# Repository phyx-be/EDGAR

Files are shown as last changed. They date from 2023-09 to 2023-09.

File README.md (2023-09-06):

# EDGAR
EDGAR is a PoE to EtherCAT P module delivering 300mA on the Us rail and 660mA on the Up rail. However, during bootup it will keep the Up rail disabled and boost the current limit of the Us rail to 745mA in order to ensure proper startup of the connected modules. Keep in mind that the power will only be enabled if an 802.3at PoE PSE is detected.

The board is built around the [Silvertel AG5424](https://silvertel.com/ag5400/), 30W 24V DC PoE module and implements 2 [Texas Instruments TPS26625](https://www.ti.com/product/TPS2662) eFuses for splitting the power rail.

# REV 00
First prototype to verify the working principle using an M8-D coded 10/100 Ethernet connector and a M8-P Coded EtherCAT P connector.

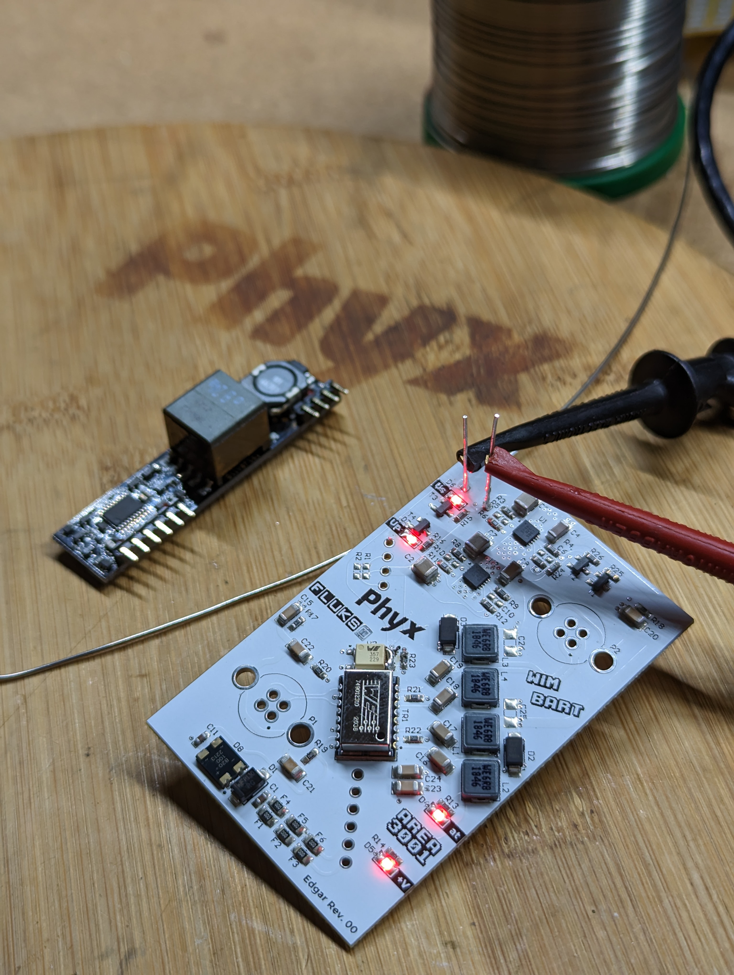
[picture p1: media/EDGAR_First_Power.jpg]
DC Power test


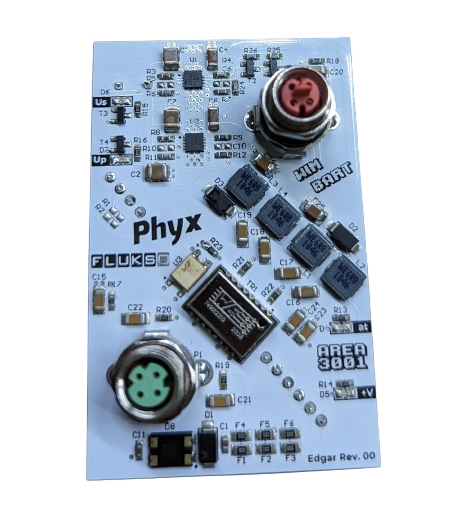
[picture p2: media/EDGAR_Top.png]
Board Top View


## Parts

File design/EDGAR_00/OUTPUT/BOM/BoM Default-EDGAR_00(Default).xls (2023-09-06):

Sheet: BOM Report
Bill of Materials |  |  | Edgar
Project: |  | EDGAR_00.PrjPcb
Revision: |  | 00
Variant: |  | Default
Creation Date: | 13/05/2023 | 23:49
Print Date: | 2023-09-07 | 0:11:15
Footprint | Comment | LibRef | Designator | Value | Description | Supplier 1 | Supplier Part Number 1 | Supplier 2 | Supplier Part Number 2 | Supplier 3 | Supplier Part Number 3 | Quantity
C0603_N |  | CAP # 22nF 100V 0603 X7R | C1, C11 | 22nF 100V X7R | CAP # 22nF 100V 0603 X7R | Farnell | 2346911 | Farnell | 3581381 | Digi-Key | 445-2275-1-ND | 2
C1210_N |  | CAP # 4u7F 50V 1210 X7R | C2, C3, C7 | 4u7F 50V | CAP # 4u7F 50V 1210 X7R | Farnell | 1828841 | Digi-key | 1276-1292-1-ND |  |  | 3
C1206_N |  | CAP # 22uF 35V 1206 X5R | C4, C8 | 22uF 35V | CAP # 22uF 35V 1206 X5R | Digi-key | 445-8045-1-ND |  |  | Generic | 22uF 35V 1206 X7R | 2
C1206_N |  | CAP # 1nF 2kV 1206 | C15, C20 | 1nF 2kV | CAP # 1nF 2kV 1206 | Digi-key | 732-885342208018CT-ND |  |  |  |  | 2
C1206_N |  | CAP # 1uF 100V 1206 | C16, C17, C18, C19 | 1uF 100V | CAP # 1uF 100V 1206 | Farnell | 1735543 | Digi-key | 1276-1838-1-ND | Generic | 1uF 100V 1206 X7R | 4
C1206_N |  | CAP # 10nF 250V 1206 | C21, C22, C23, C24 | 10nF 250V | CAP # 10nF 250V 1206 | Farnell | 2852359 | Digi-key | 732-12089-1-ND | Generic | 10nF 250V 1206 X7R | 4
C1206_N |  | CAP # 10uF 50V 1206 | C25, C26 | 10uF 50V | CAP # 10uF 50V 1206 | Farnell | 2382682 | Digi-key | 1276-6736-1-ND | Generic | 10uF 50V 1206 X7R | 2
C_12.5x14_5mm | URZ1V471MHD | CAP 470uF 35V 12.5x14mm | C27 | 470uF 35V | CAP 470uF 35V 12.5x14mm | Digi-key | 493-15958-ND |  |  |  |  | 1
SMA_AC | TVS Diode 58V 400W Unidirectional DO-214AC SMA | TVS # UNI 58V SMAJ58A | D1 | SMAJ58A | TVS # UNI 58V SMAJ58A | Farnell | 1579005 | Digi-key | 732-SMAJ58ACT-ND |  |  | 1
SMA_AC | TVS Diode 24V 400W Unidirectional DO-214AC SMA | TVS # UNI 24V SMAJ24A | D2, D3 | SMAJ24A | TVS # UNI 24V SMAJ24A | Farnell | 2675296 | Digi-key | SMAJ24ALFCT-ND |  |  | 2
LED_0805_GR | Default 0805 Green LED | LED # Green 0805 | D4, D5, D6, D7 |  | LED # Green 0805 | Farnell | 2099239 |  |  |  |  | 4
BRNS_CD_HD2x | Bridge Rectifier 100V 2A CD-HD201 | BRIDGE # CD-HD201 | D8 | CD-HD201 | BRIDGE # CD-HD201 | Digi-key | CD-HD201CT-ND |  |  |  |  | 1
L0805 |  | FER # 600R 2A 0805 0R10 | F1, F2, F3, F4, F5, F6 | 2A 0R1 | FER # 600R 2A 0805 0R10 | Farnell | 1838838 | Farnell | 2475050 | LCSC | C139168 | 6
WE_WE-LHMI_5020 | 74437334068 | IND # 6u8H 5.2x5.2 WE-LHMI 5020 | L1, L2, L3, L4 | 6u8H | IND # 6u8H 5.2x5.2 WE-LHMI 5020 | Digi-key | 732-6156-1-ND | Farnell | 2467217 | Mouser | 710-74437334068 | 4
SIL_Ag5400 | PoE+ Module 24V 30W 802.3at Silvertel Ag5424 | PWR # MOD PoE 802.3at 30W 24V Ag5424 | MOD1 | Ag5424 | PWR # MOD PoE 802.3at 30W 24V Ag5424 | Mouser | 480-AG5424 |  |  |  |  | 1
ESCHA_8089337 | Receptacle, M8, female, straight, 4 poles, D-coded, back wall-mounting, print contact, shielded, Industrial Ethernet | M8 D IE-FHM8KSD4-P | P1 | IE-FHM8KSD4-P/M10 | M8 D IE-FHM8KSD4-P |  |  |  |  |  |  | 1
ESCHA_8089341 | Receptacle, M8, female, straight, 4 poles, P-coded, back wall-mounting, print contact, shielded, EtherCATP | M8 P IE-FHM8KSP4-P | P2 | IE-FHM8KSP4-P/M10 | M8 P IE-FHM8KSP4-P |  |  |  |  |  |  | 1
R0603_N |  | RES # 1M 0603 | R3, R8, R17, R18 | 1M | RES # 1M 0603 |  |  |  |  | Generic | 1M 1% 0603 | 4
R0603_N |  | RES # 10K 0603 | R4, R12, R13, R14, R15, R16, R26 | 10K | RES # 10K 0603 | Farnell | 2502397 | LCSC | C25804 | Generic | 10K 1% 0603 | 7
R0603_N |  | RES # 0R 0603 | R6, R11, R24 | 0R | RES # 0R 0603 | Farnell | 2447743 | LCSC | C95177 | Generic | 0R 1% 0603 | 3
R0603_N |  | RES # 22K 0603 | R7 | 22K | RES # 22K 0603 |  |  |  |  | Generic | 22K 1% 0603 | 1
R0603_N |  | RES # 100K 0603 | R9, R23 | 100K | RES # 100K 0603 |  |  |  |  | Generic | 100K 1% 0603 | 2
R0603_N |  | RES # 75R 0603 | R19, R20, R21, R22 | 75R | RES # 75R 0603 | Digi-key | 311-75.0HRCT-ND |  |  | Generic | 75R 1% 0603 | 4
R0603_N |  | RES # 15K 0603 | R25 | 15K | RES # 15K 0603 |  |  |  |  | Generic | 15K 1% 0603 | 1
SOT23-3 | 0.12A N-Ch MOSFET 60V Vgs 2.5 | 2N7002 N-Ch MOSFET 0.12A 2.5Vgs 60Vds SOT23 | T1, T2, T3, T4 | 2N7002 | 2N7002 N-Ch MOSFET 0.12A 2.5Vgs 60Vds SOT23 | Farnell | 9845313 | Digi-key | 1514-2N7002TRPBFREECT-ND |  |  | 4
WE_749012310 | 10/100 Ethernet transformer with720mA PoE | TR # 749012310 WE-LAN AQ | TR1 | 749012310 | TR # 749012310 WE-LAN AQ | Farnell | 4066195 | Digi-key | 732-749012310CT-ND | Mouser | 710-749012310 | 1
TI_DRC10 | 4.5-V to 60-V, 478mΩ, 0.025-0.88A eFuse, auto retry, input and output reverse polarity protection | EFUSE # TPS26625 60V 880mA | U1, U2 | TPS26625 | EFUSE # TPS26625 60V 880mA | Digi-key | 296-52606-1-ND | Ti | TPS26625DRCR |  |  | 2
WE_WL-OCPT_SOP-4 | CTR 50~600, 35V Vce, 60mA, 3.75kV | OPTO # 140357145000 | U3 | 140357145000 | OPTO # 140357145000 | Digi-key | 732-140357145000CT-ND | Wurth | 140357145000 |  |  | 1
 |  |  |  |  |  |  |  |  |  |  |  | 71
Approved |  | Notes

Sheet: BOM Print
Footprint | Comment | LibRef | Designator | Value | Description | Quantity | 3
C0603_N |  | CAP # 22nF 100V 0603 X7R | C1, C11 | 22nF 100V X7R | CAP # 22nF 100V 0603 X7R | 2 | 6
C1210_N |  | CAP # 4u7F 50V 1210 X7R | C2, C3, C7 | 4u7F 50V | CAP # 4u7F 50V 1210 X7R | 3 | 9
C1206_N |  | CAP # 22uF 35V 1206 X5R | C4, C8 | 22uF 35V | CAP # 22uF 35V 1206 X5R | 2 | 6
C1206_N |  | CAP # 1nF 2kV 1206 | C15, C20 | 1nF 2kV | CAP # 1nF 2kV 1206 | 2 | 6
C1206_N |  | CAP # 1uF 100V 1206 | C16, C17, C18, C19 | 1uF 100V | CAP # 1uF 100V 1206 | 4 | 12
C1206_N |  | CAP # 10nF 250V 1206 | C21, C22, C23, C24 | 10nF 250V | CAP # 10nF 250V 1206 | 4 | 12
C1206_N |  | CAP # 10uF 50V 1206 | C25, C26 | 10uF 50V | CAP # 10uF 50V 1206 | 2 | 6
C_12.5x14_5mm | URZ1V471MHD | CAP 470uF 35V 12.5x14mm | C27 | 470uF 35V | CAP 470uF 35V 12.5x14mm | 1 | 3
SMA_AC | TVS Diode 58V 400W Unidirectional DO-214AC SMA | TVS # UNI 58V SMAJ58A | D1 | SMAJ58A | TVS # UNI 58V SMAJ58A | 1 | 3
SMA_AC | TVS Diode 24V 400W Unidirectional DO-214AC SMA | TVS # UNI 24V SMAJ24A | D2, D3 | SMAJ24A | TVS # UNI 24V SMAJ24A | 2 | 6
LED_0805_GR | Default 0805 Green LED | LED # Green 0805 | D4, D5, D6, D7 |  | LED # Green 0805 | 4 | 12
BRNS_CD_HD2x | Bridge Rectifier 100V 2A CD-HD201 | BRIDGE # CD-HD201 | D8 | CD-HD201 | BRIDGE # CD-HD201 | 1 | 3
L0805 |  | FER # 600R 2A 0805 0R10 | F1, F2, F3, F4, F5, F6 | 2A 0R1 | FER # 600R 2A 0805 0R10 | 6 | 18
WE_WE-LHMI_5020 | 74437334068 | IND # 6u8H 5.2x5.2 WE-LHMI 5020 | L1, L2, L3, L4 | 6u8H | IND # 6u8H 5.2x5.2 WE-LHMI 5020 | 4 | 12
SIL_Ag5400 | PoE+ Module 24V 30W 802.3at Silvertel Ag5424 | PWR # MOD PoE 802.3at 30W 24V Ag5424 | MOD1 | Ag5424 | PWR # MOD PoE 802.3at 30W 24V Ag5424 | 1 | 3
ESCHA_8089337 | Receptacle, M8, female, straight, 4 poles, D-coded, back wall-mounting, print contact, shielded, Industrial Ethernet | M8 D IE-FHM8KSD4-P | P1 | IE-FHM8KSD4-P/M10 | M8 D IE-FHM8KSD4-P | 1 | 3
ESCHA_8089341 | Receptacle, M8, female, straight, 4 poles, P-coded, back wall-mounting, print contact, shielded, EtherCATP | M8 P IE-FHM8KSP4-P | P2 | IE-FHM8KSP4-P/M10 | M8 P IE-FHM8KSP4-P | 1 | 3
R0603_N |  | RES # 1M 0603 | R3, R8, R17, R18 | 1M | RES # 1M 0603 | 4 | 12
R0603_N |  | RES # 10K 0603 | R4, R12, R13, R14, R15, R16, R26 | 10K | RES # 10K 0603 | 7 | 21
R0603_N |  | RES # 0R 0603 | R6, R11, R24 | 0R | RES # 0R 0603 | 3 | 9
R0603_N |  | RES # 22K 0603 | R7 | 22K | RES # 22K 0603 | 1 | 3
R0603_N |  | RES # 100K 0603 | R9, R23 | 100K | RES # 100K 0603 | 2 | 6
R0603_N |  | RES # 75R 0603 | R19, R20, R21, R22 | 75R | RES # 75R 0603 | 4 | 12
R0603_N |  | RES # 15K 0603 | R25 | 15K | RES # 15K 0603 | 1 | 3
SOT23-3 | 0.12A N-Ch MOSFET 60V Vgs 2.5 | 2N7002 N-Ch MOSFET 0.12A 2.5Vgs 60Vds SOT23 | T1, T2, T3, T4 | 2N7002 | 2N7002 N-Ch MOSFET 0.12A 2.5Vgs 60Vds SOT23 | 4 | 12
WE_749012310 | 10/100 Ethernet transformer with720mA PoE | TR # 749012310 WE-LAN AQ | TR1 | 749012310 | TR # 749012310 WE-LAN AQ | 1 | 3
TI_DRC10 | 4.5-V to 60-V, 478mΩ, 0.025-0.88A eFuse, auto retry, input and output reverse polarity protection | EFUSE # TPS26625 60V 880mA | U1, U2 | TPS26625 | EFUSE # TPS26625 60V 880mA | 2 | 6
WE_WL-OCPT_SOP-4 | CTR 50~600, 35V Vce, 60mA, 3.75kV | OPTO # 140357145000 | U3 | 140357145000 | OPTO # 140357145000 | 1 | 3

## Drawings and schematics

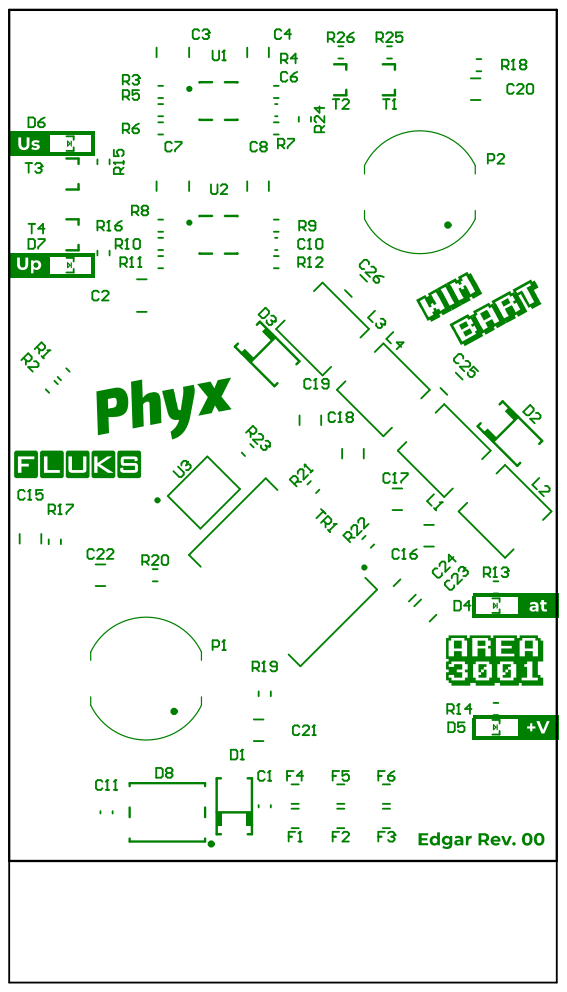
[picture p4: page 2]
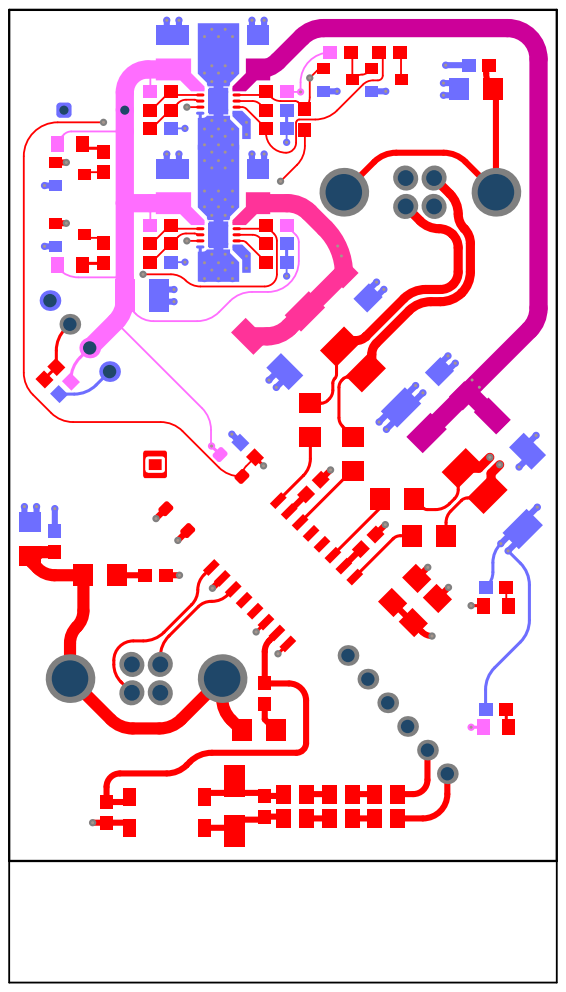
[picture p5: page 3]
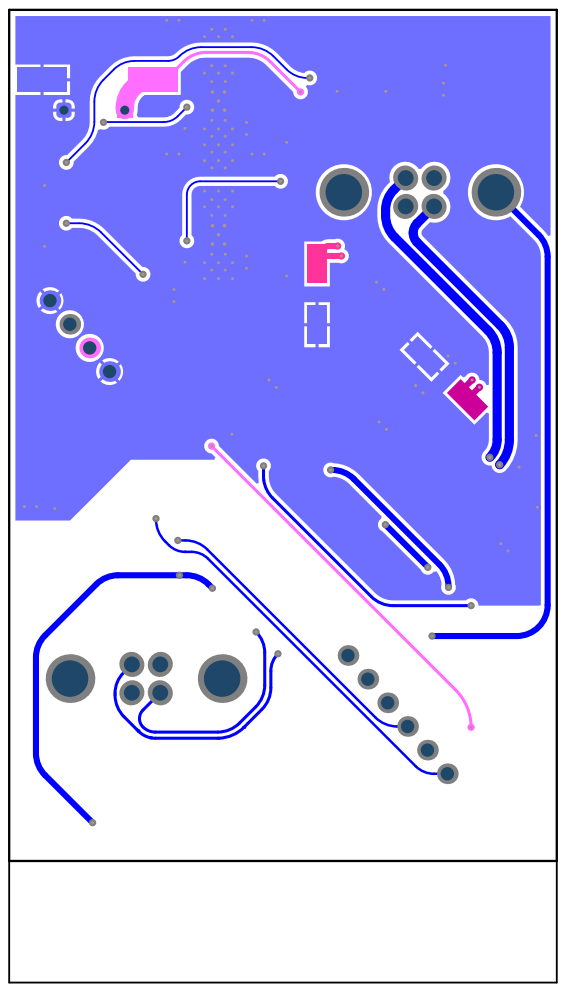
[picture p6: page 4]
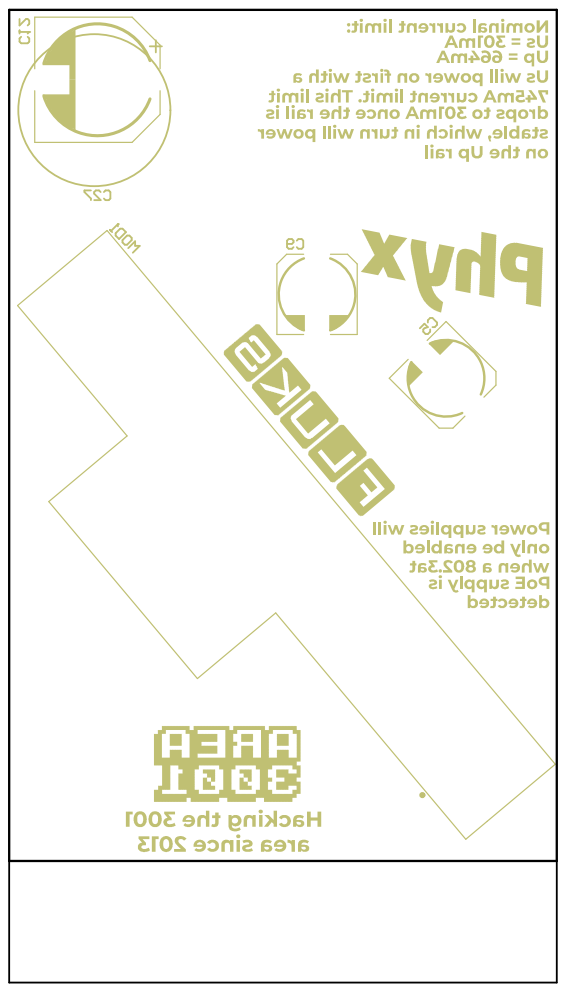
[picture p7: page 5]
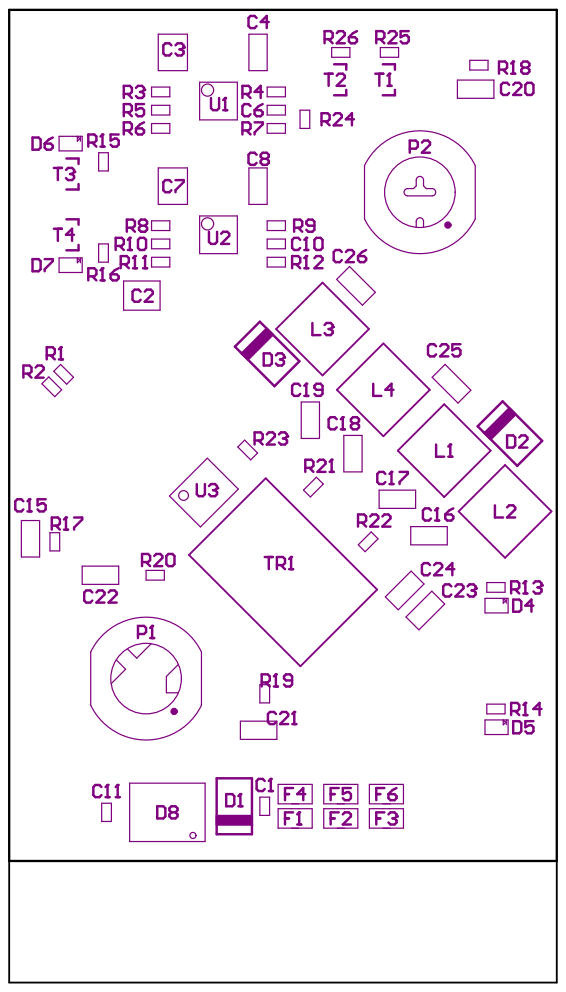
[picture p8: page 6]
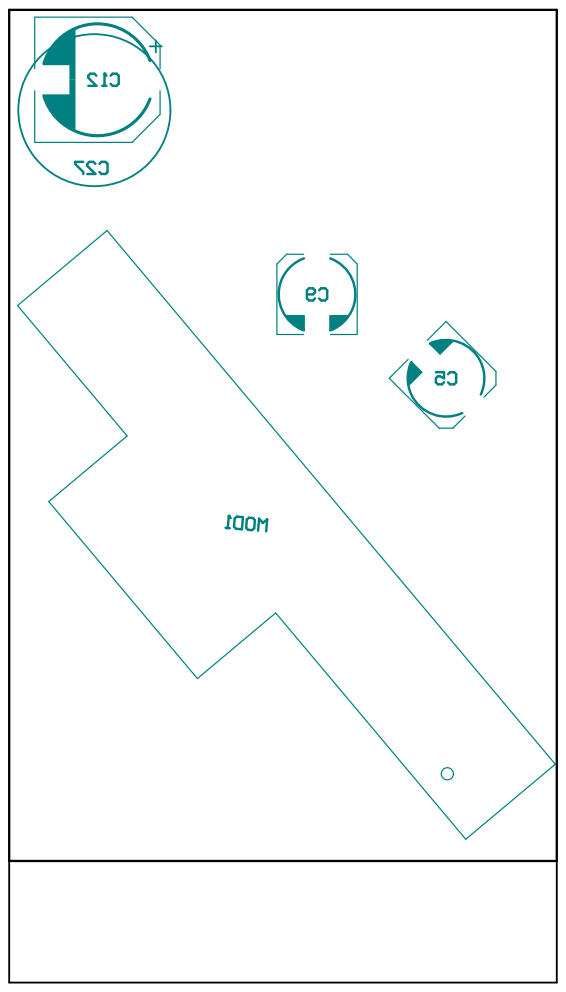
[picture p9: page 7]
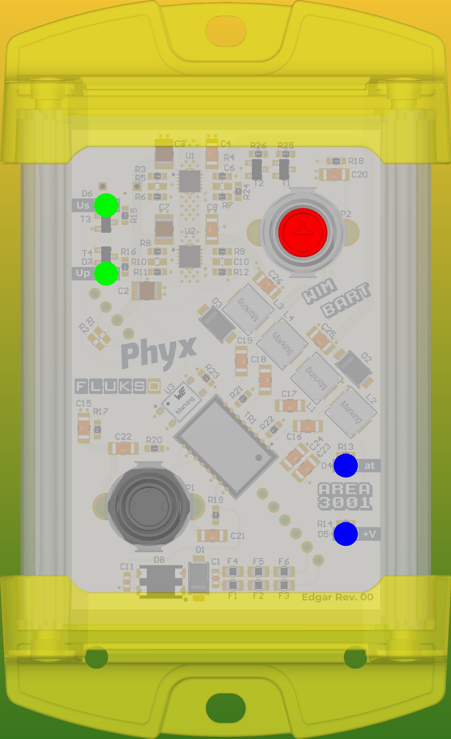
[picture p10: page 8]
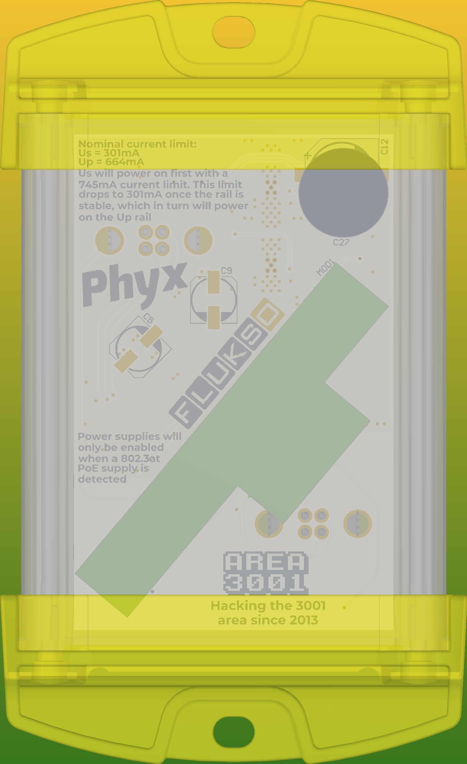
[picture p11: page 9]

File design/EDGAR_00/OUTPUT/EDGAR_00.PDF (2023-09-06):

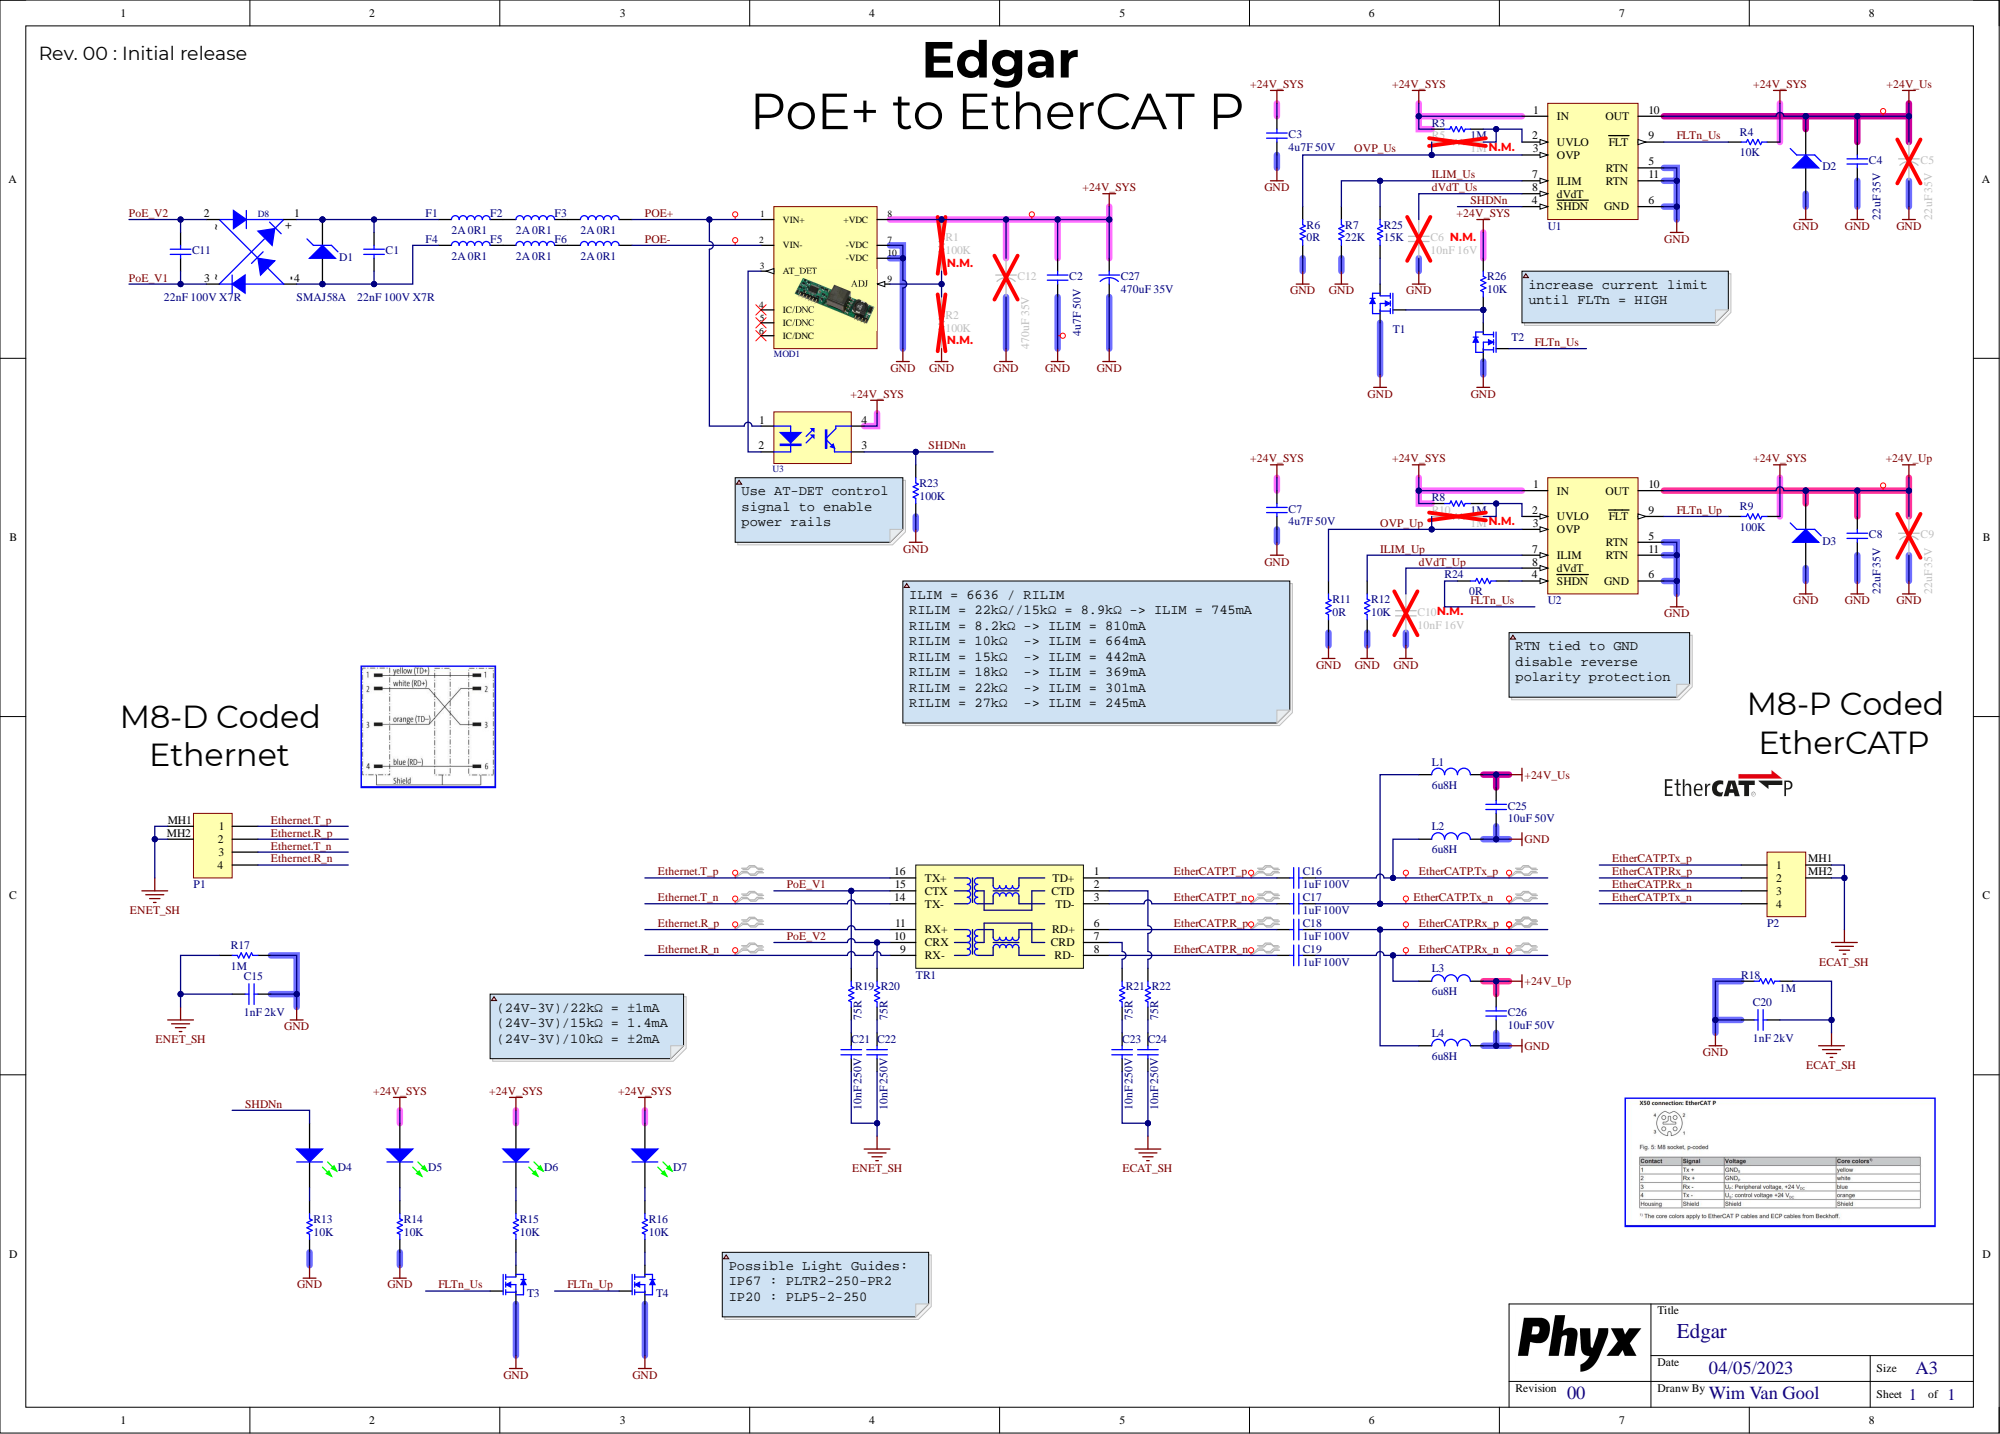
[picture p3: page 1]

Edgar Rev. 00 : Initial release

N.M. 1M | | OVP 3

ILIM_Us | dVdT 8 ILIM 7
dVdT_Us

SHDNn | | SHDN 4

Use AT-DET control
signal to enable
power rails

ILIM_Up | | dVdT 8 ILIM 7

dVdT_Up
R24 | | SHDN 4

RTN tied to GND
disable reverse
polarity protection

RX+ 11
CRX 10
RX- 9
